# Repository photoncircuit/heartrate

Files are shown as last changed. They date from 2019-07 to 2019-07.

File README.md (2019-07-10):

# Heart Rate Monitoring System
Bachelors degree final project: portable heart rate monitoring system with bluetooth data transfer capability

The aim of this project is to design and construct a functional heart rate monitoring system. The device will amplify pulse measurements taken from an individual’s fingertip. The system is based on an active band pass filter which will amplify a selected signal frequency while attenuating noise and interference. Signals acquired from the fingertip sensor will be analogue and require conversion to digital. The use of an analogue to digital convertor (ADC) is employed in order for the microcontroller to process the information taken from the individual. After processing, the microcontroller will display pulse rate data on an LCD display and transmit the information wirelessly through the use of the Bluetooth communication protocol. It enables the user to move the device to any area desirable within their homes. A user can then view the transmitted data on an application, using a graphical user interface, running on their personal computers. Implementing this technology allows for users to easily monitor and log data about their personal health. The results collected from thorough testing indicate that even with precautions taken, noise and interference are still major causes of signal corruption.

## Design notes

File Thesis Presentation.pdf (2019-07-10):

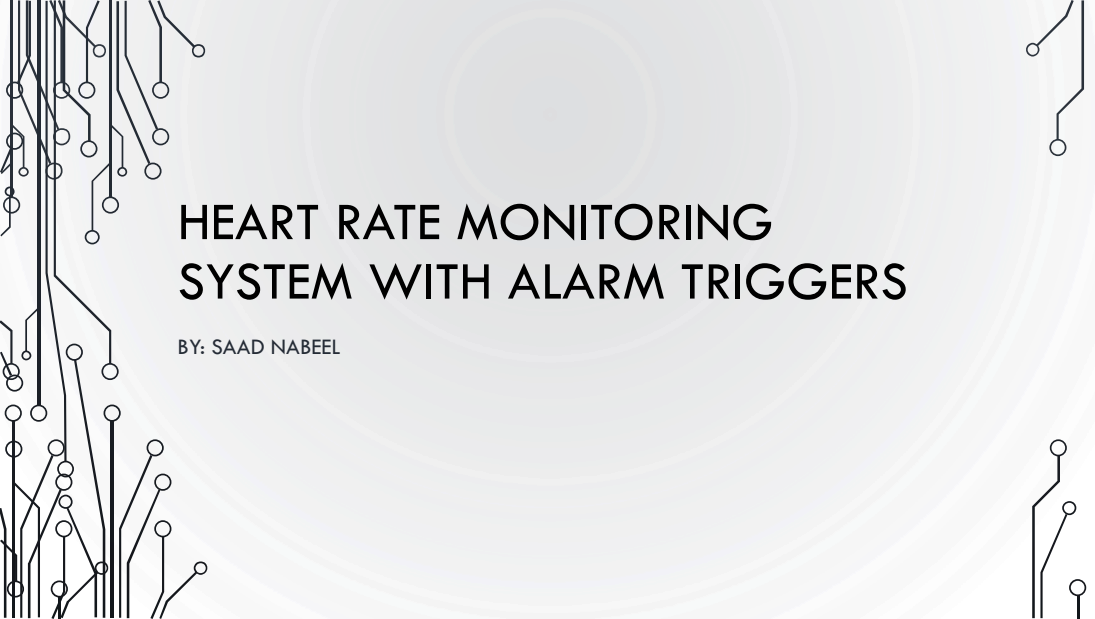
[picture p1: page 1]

HEART RATE MONITORING
SYSTEM WITH ALARM TRIGGERS

BY: SAAD NABEEL

# TABLE OF CONTENTS

## - Motivation

## - Objectives

## - Methodology

## - Specifications

## - Signal Conditioning

## - Analogue to Digital Conversion (ADC)

## - Schematic Diagram (Complete Circuit)

## - PIN Connections

## - Testing and Results

# MOTIVATION

## - Preventative measure for cardiac

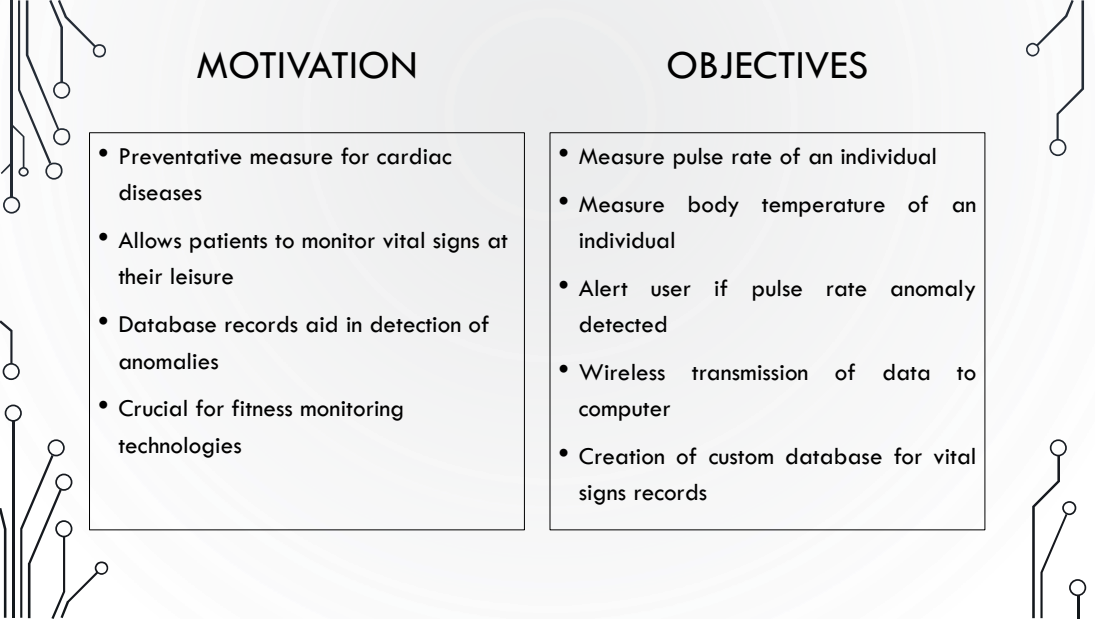
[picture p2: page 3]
OBJECTIVES; • Wireless transmission of; data to

• Measure pulse rate of an individual

diseases
• Allows patients to monitor vital signs at
their leisure
• Database records aid in detection of
anomalies
• Crucial for fitness monitoring
technologies

• Measure body temperature of an
individual
• Alert user if pulse rate anomaly
detected
computer
• Creation of custom database for vital
signs records

# METHODOLOGY

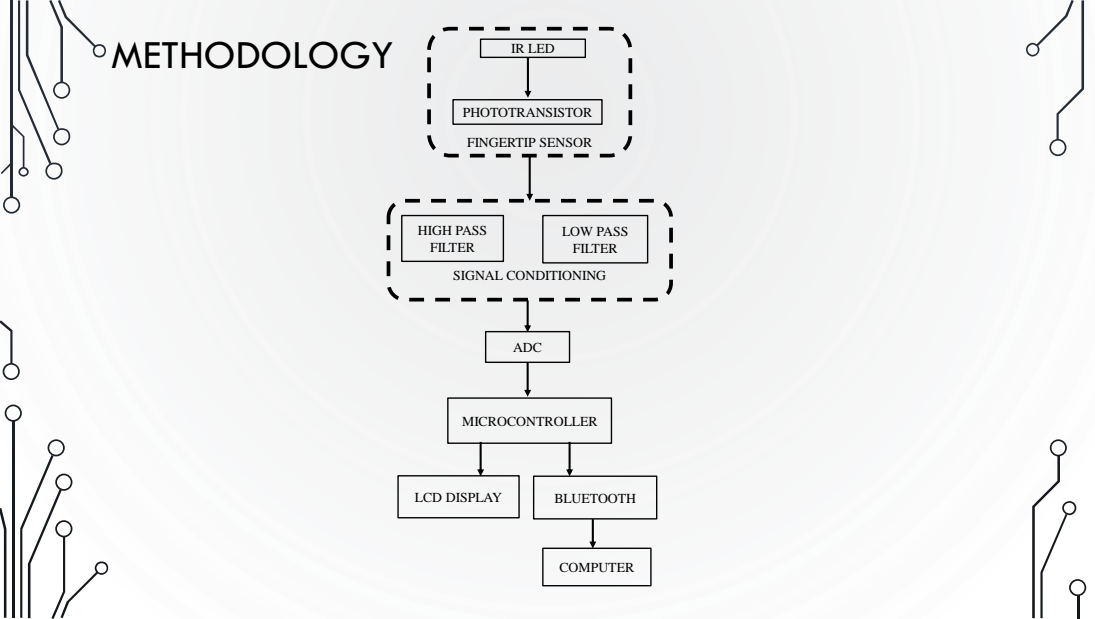
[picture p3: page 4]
FINGERTIP SENSOR; HIGH PASS FILTER; LOW PASS FILTER; SIGNAL CONDITIONING; ADC; MICROCONTROLLER; LCD DISPLAY; BLUETOOTH; COMPUTER; IR LED; PHOTOTRANSISTOR

# SPECIFICATIONS: OPTICAL SENSOR

## Main components: Infrared LED & Phototransistor

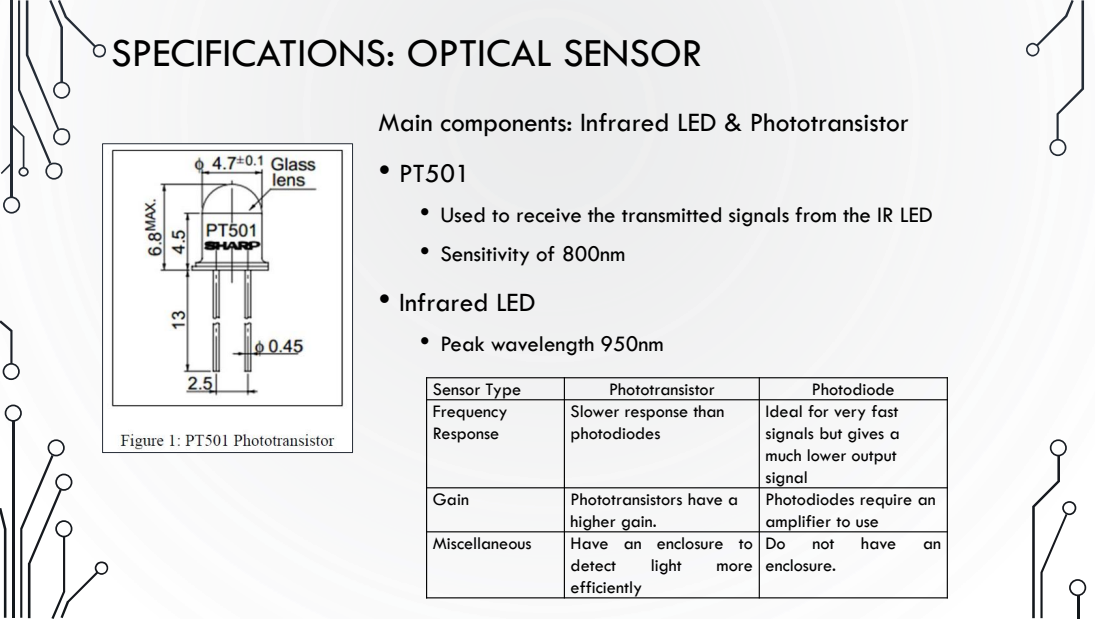
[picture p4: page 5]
• Sensitivity of 800nm; • Infrared LED; • Peak wavelength 950nm

• Used to receive the transmitted signals from the IR LED

Sensor Type | Phototransistor | Photodiode
Frequency Response | Slower response than photodiodes | Ideal for very fast signals but gives a much lower output signal

Gain | Phototransistors have a higher gain. | Photodiodes require an amplifier to use

Miscellaneous | Have an enclosure to detect light more efficiently | Do not have an enclosure.

# SPECIFICATIONS: OPERATIONAL AMPLIFIER

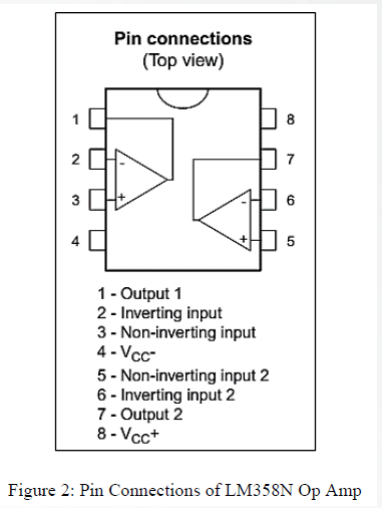
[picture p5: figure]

### - LM358N Operational Amplifier

### - Changes of blood volume picked up by the IR LED &

### phototransistor are too small to be read by microcontroller

### - Signal must be amplified in order to collect measurements

# SPECIFICATIONS: WIRELESS TRANSMISSION

### - Operating voltage: 3.3V

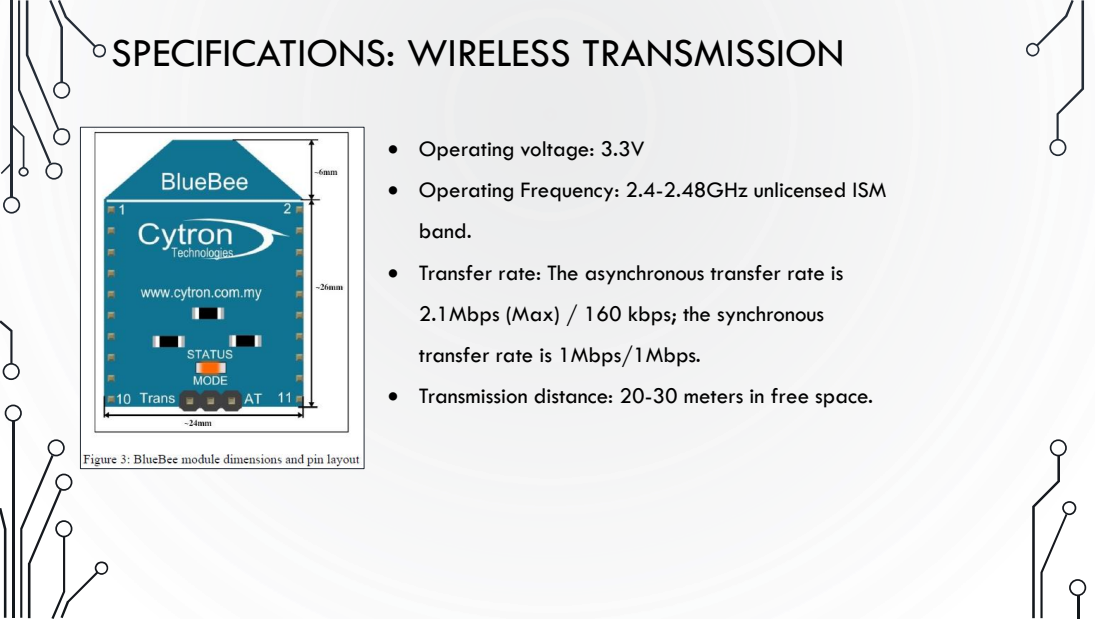
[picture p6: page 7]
band.

• Operating Frequency: 2.4-2.48GHz unlicensed ISM

• Transfer rate: The asynchronous transfer rate is

2.1Mbps (Max) / 160 kbps; the synchronous

transfer rate is 1Mbps/1Mbps.

• Transmission distance: 20-30 meters in free space.

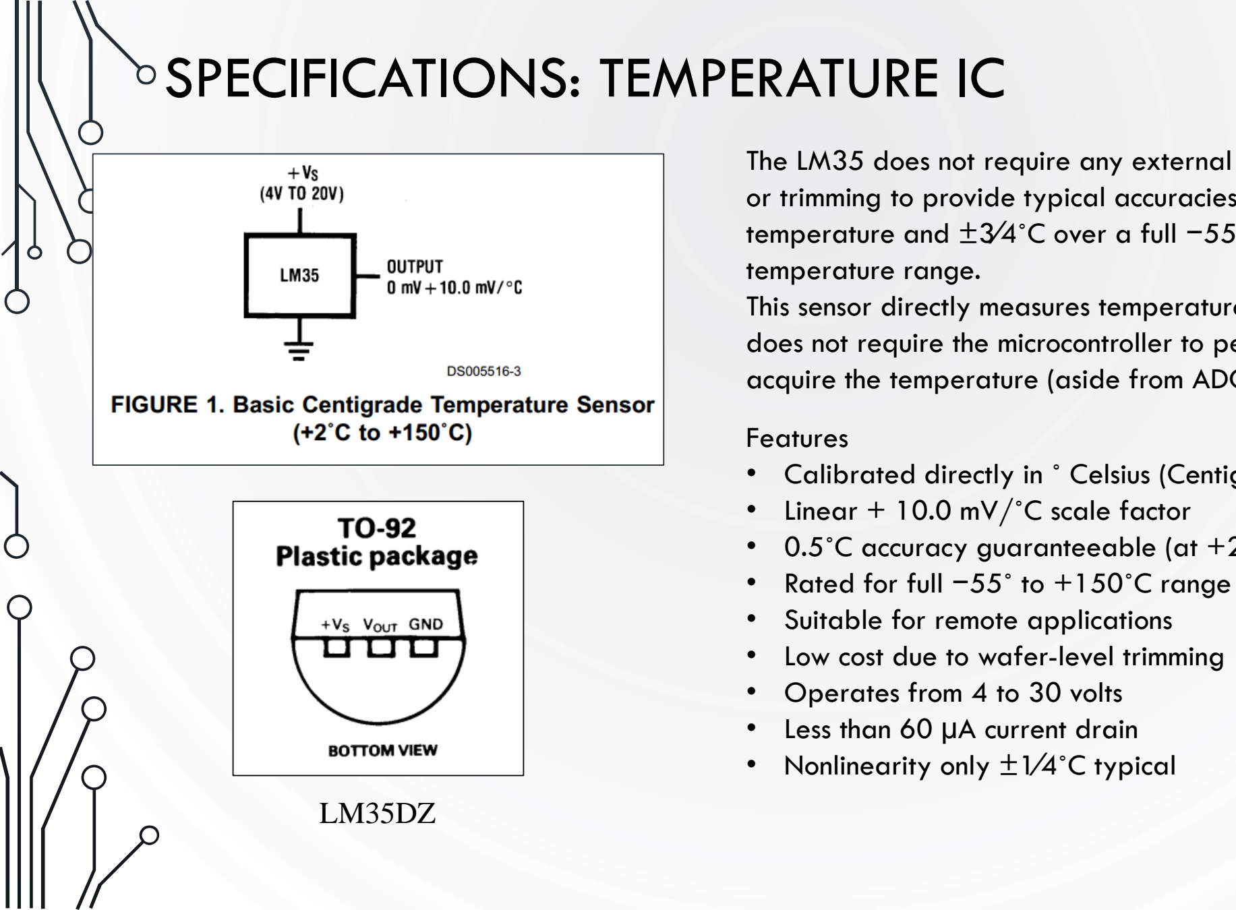
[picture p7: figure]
SPECIFICATIONS: TEMPERATURE IC; temperature range.; Features; • Linear + 10.0 mV/˚C scale factor; • Rated for full −55˚ to +150˚C range • Suitable for remote applications • Low cost due to wafer-level trimming • Operates from 4 to 30 volts • Less than 60 µA current drain • Nonlinearity only ±1⁄4˚C typical

The LM35 does not require any external calibration
or trimming to provide typical accuracies of ±1⁄4˚C at room temperature and ±3⁄4˚C over a full −55 to +150˚C

This sensor directly measures temperature in degrees Celsius and does not require the microcontroller to perform any equations to acquire the temperature (aside from ADC).

- Calibrated directly in ˚ Celsius (Centigrade)
- 0.5˚C accuracy guaranteeable (at +25˚C)

# SPECIFICATIONS: MICROCONTROLLER

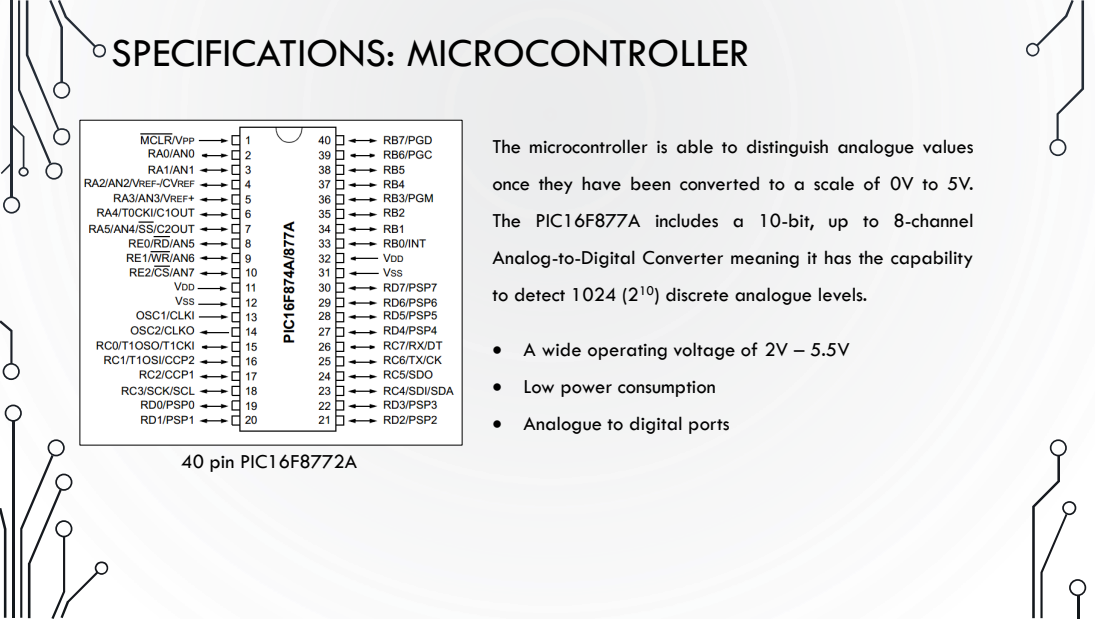
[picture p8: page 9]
to detect 1024 (2; 40 pin PIC16F8772A

The microcontroller is able to distinguish analogue values

once they have been converted to a scale of 0V to 5V.

The PIC16F877A includes a 10-bit, up to 8-channel

Analog-to-Digital Converter meaning it has the capability

10) discrete analogue levels.

• A wide operating voltage of 2V – 5.5V

• Low power consumption

• Analogue to digital ports

# SIGNAL CONDITIONING: LOW PASS FILTER

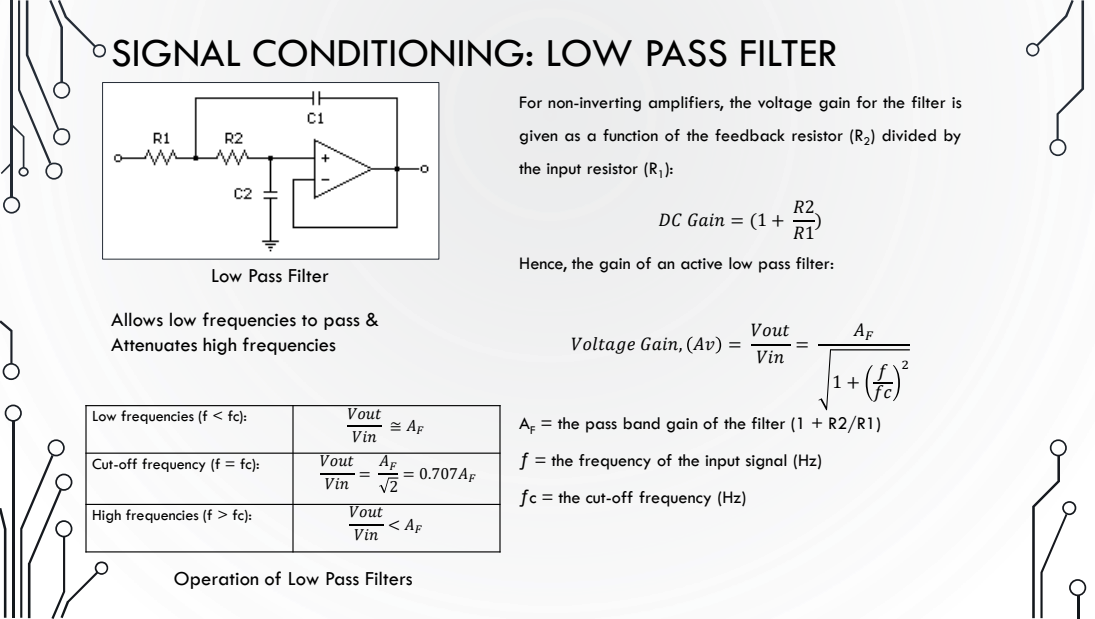
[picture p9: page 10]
) divided by; DC Gain = (1 +; Vout Vin =

For non-inverting amplifiers, the voltage gain for the filter is

given as a function of the feedback resistor (R2

the input resistor (R1

Hence, the gain of an active low pass filter:

Low Pass Filter

Allows low frequencies to pass &
Attenuates high frequencies

Voltage Gain, Av =

Low frequencies (f < fc): | Vout ≅ AF Vin

= the pass band gain of the filter (1 + R2/R1)

Cut-off frequency (f = fc): | Vout AF Vin = = 0.707AF 2

ƒ = the frequency of the input signal (Hz)

ƒc = the cut-off frequency (Hz)

High frequencies (f > fc): | Vout Vin < AF

Operation of Low Pass Filters

# SIGNAL CONDITIONING: HIGH PASS FILTER

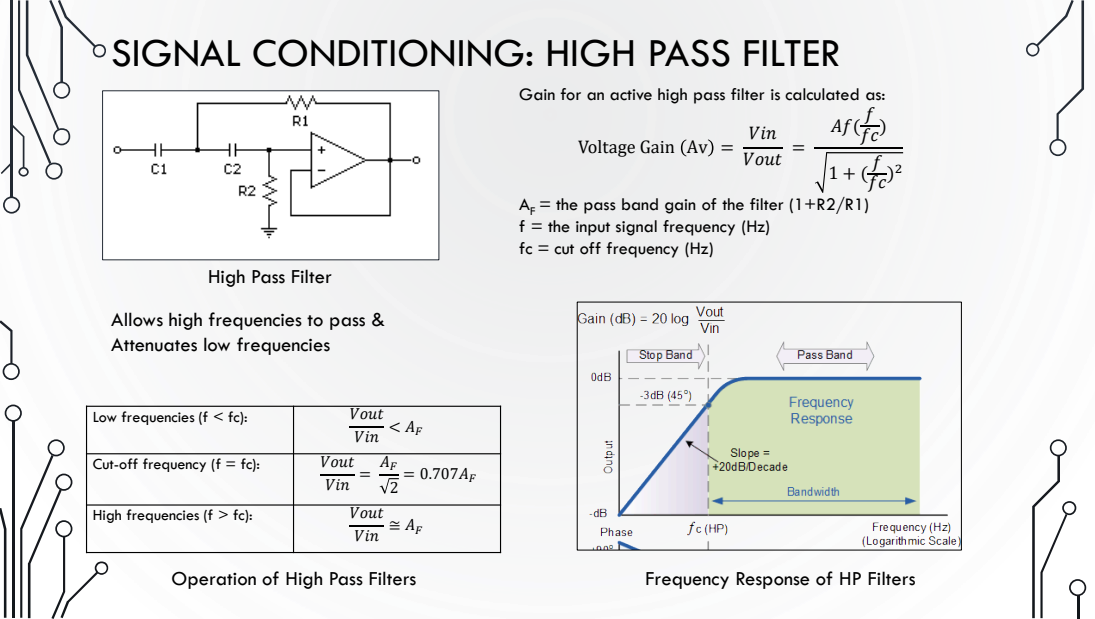
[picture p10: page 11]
Vin Vout =; Operation of High Pass Filters; Frequency Response of HP Filters

Gain for an active high pass filter is calculated as:

Voltage Gain Av =

AF = the pass band gain of the filter (1+R2/R1)
f = the input signal frequency (Hz)
fc = cut off frequency (Hz)

High Pass Filter

Allows high frequencies to pass &
Attenuates low frequencies

Low frequencies (f < fc): | Vout Vin < AF

Cut-off frequency (f = fc): | Vout AF Vin = = 0.707AF 2

High frequencies (f > fc): | Vout ≅ AF Vin

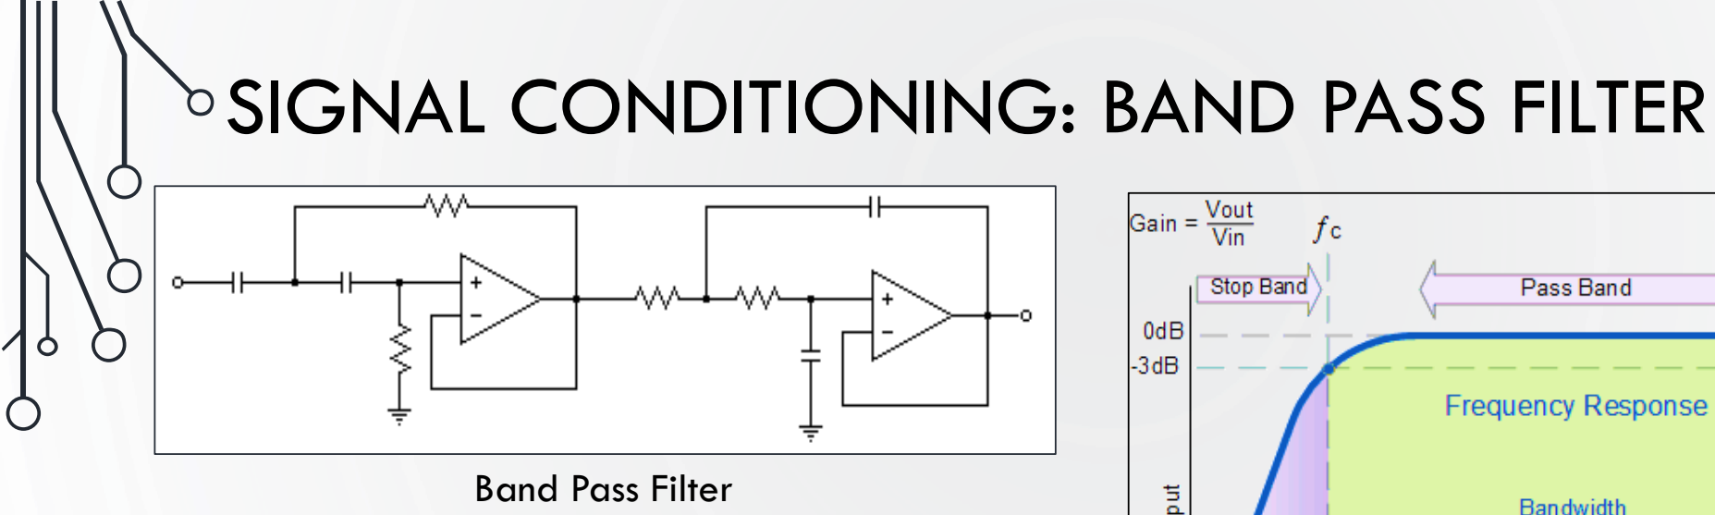
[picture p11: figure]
SIGNAL CONDITIONING: BAND PASS FILTER; Band Pass Filter

Band pass filters have two cut off frequency points which are the lower frequency and higher frequency and attenuate all other frequencies outside of these points

The cut off frequency of the low pass filter is greater than the cut off frequency of the high pass filter. The discrepancy between them at the -3dB point will decide the bandwidth of the band pass filter. The filter will block any signals outside these points.

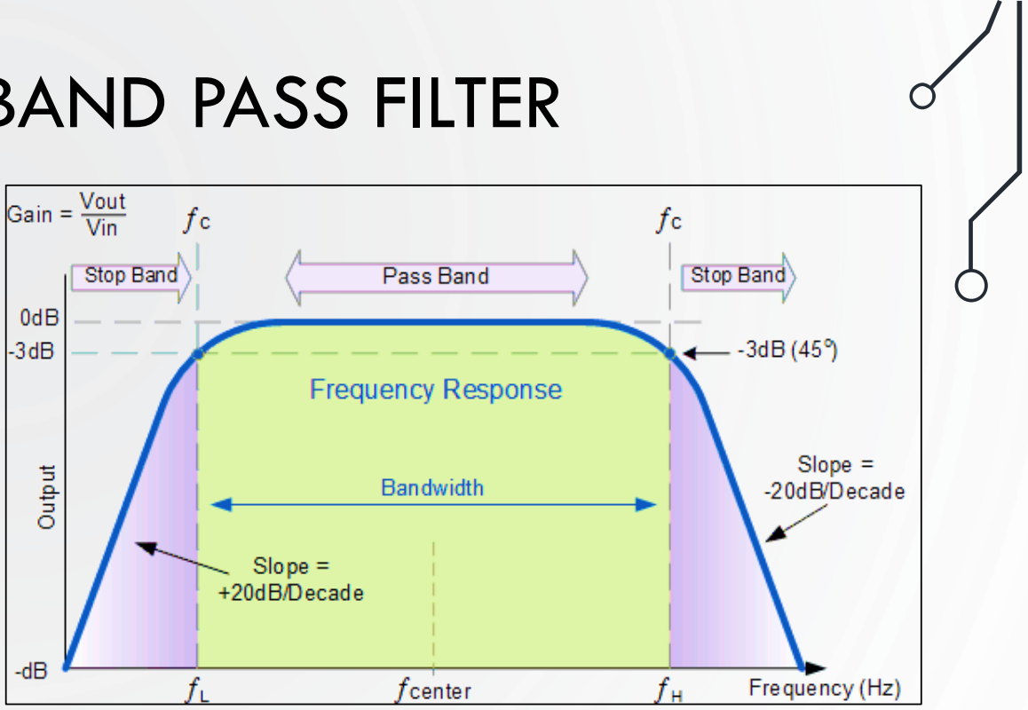
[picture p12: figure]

Frequency Response of a Band Pass Filter

The upper and lower frequencies of a band pass filter can be

found using the same formula used to calculate cut off

frequencies of high pass and low pass filters:

fc =

1
2πfRC Hz

# SIGNAL CONDITIONING: CIRCUIT

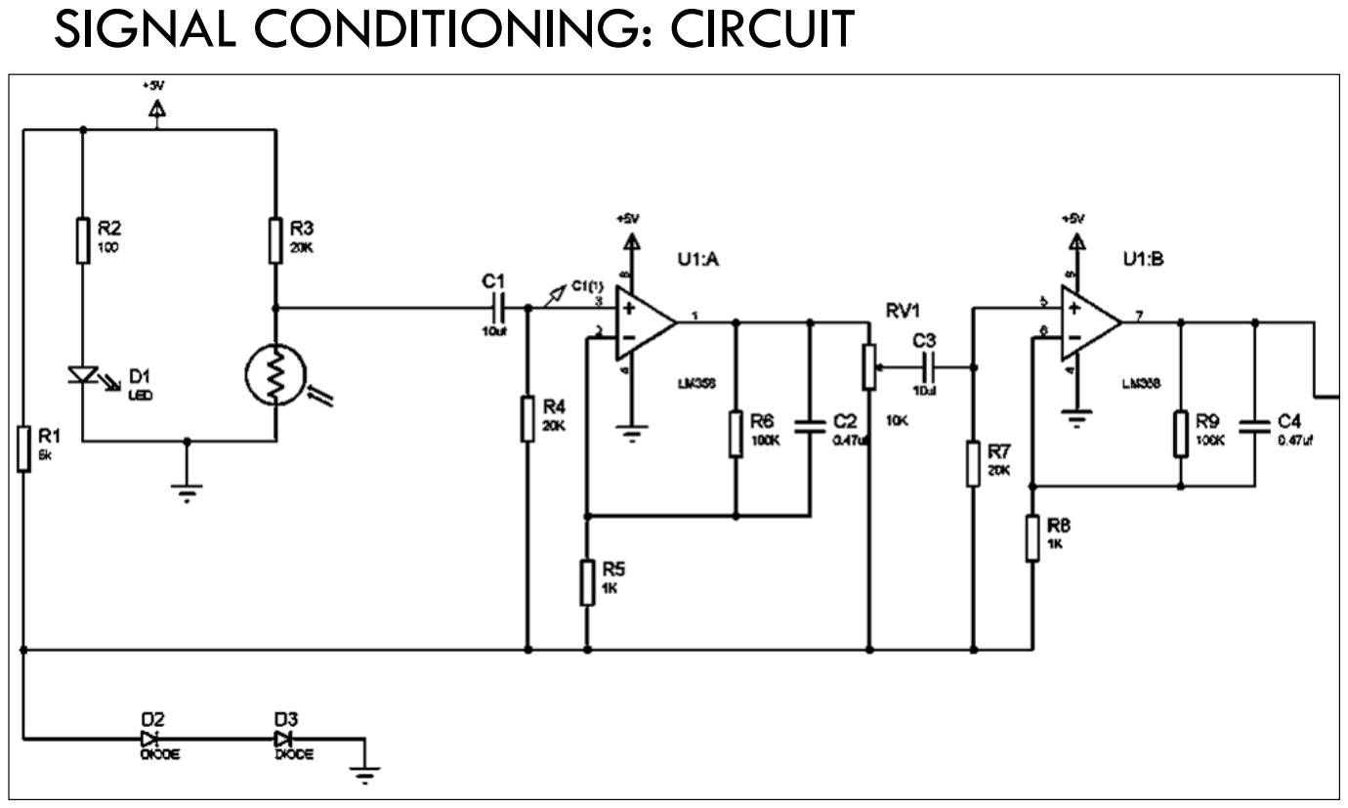
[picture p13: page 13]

# SIGNAL CONDITIONING

| Equation | Calculation
Gain of Non-Inverting Op Amp | Rf Gain Av = R1 + 1 Rf = 100KΩ R1 = 1KΩ | 100KΩ Av = 1KΩ + 1 = 101

The cut off frequency in a low pass filter is the point where high frequencies will be

attenuated and only low frequencies will be allowed to pass through. The cut off frequency

of a high pass filter is the point where only high frequencies can pass. Cascading the two

filters creates a band pass filter. To calculate the upper and lower cut off frequencies of

a band pass filter, the following equation is used:
Cut off frequency in Hertz, fc | 1 fc = 2πRC Hz R = 100KΩ C = 0.47µF | 1 fc = 2π 100KΩ 0.47µF = 3.386 Hz
Maximum Output Gain | fr² = fUpper x fLower | fr² = 3.386 Hz x 3.386 Hz = 11.464996 Hz

# ANALOGUE TO DIGITAL CONVERSION (ADC)

Code | Solution
input1 = adc_read(0)/4; if(input1>=128) | 1023/4 ≈ 255 255 128 5V = x x = 2.509 Volts If input 1 >= 2.5V, then it is HIGH
input1=adc_read(0)/4; if(input1<=45) | 255 45 = 5V x x = 0.88 Volts If input 1 <= 45, then it is LOW

Heart

Rate

The ADC conveys a ratio metric value, meaning the ADC fixes 5V to represent 1023 and anything less than 5V will be a ratio between 5V and 1023.

### Resolution of tℎe ADC System Voltage

=

### ADC Reading Analogue Voltage Measured

Since the system implemented in this project is using a 5V supply, a simple substitution can be done.

1023
5V

=

### ADC Reading Analogue Voltage Measured

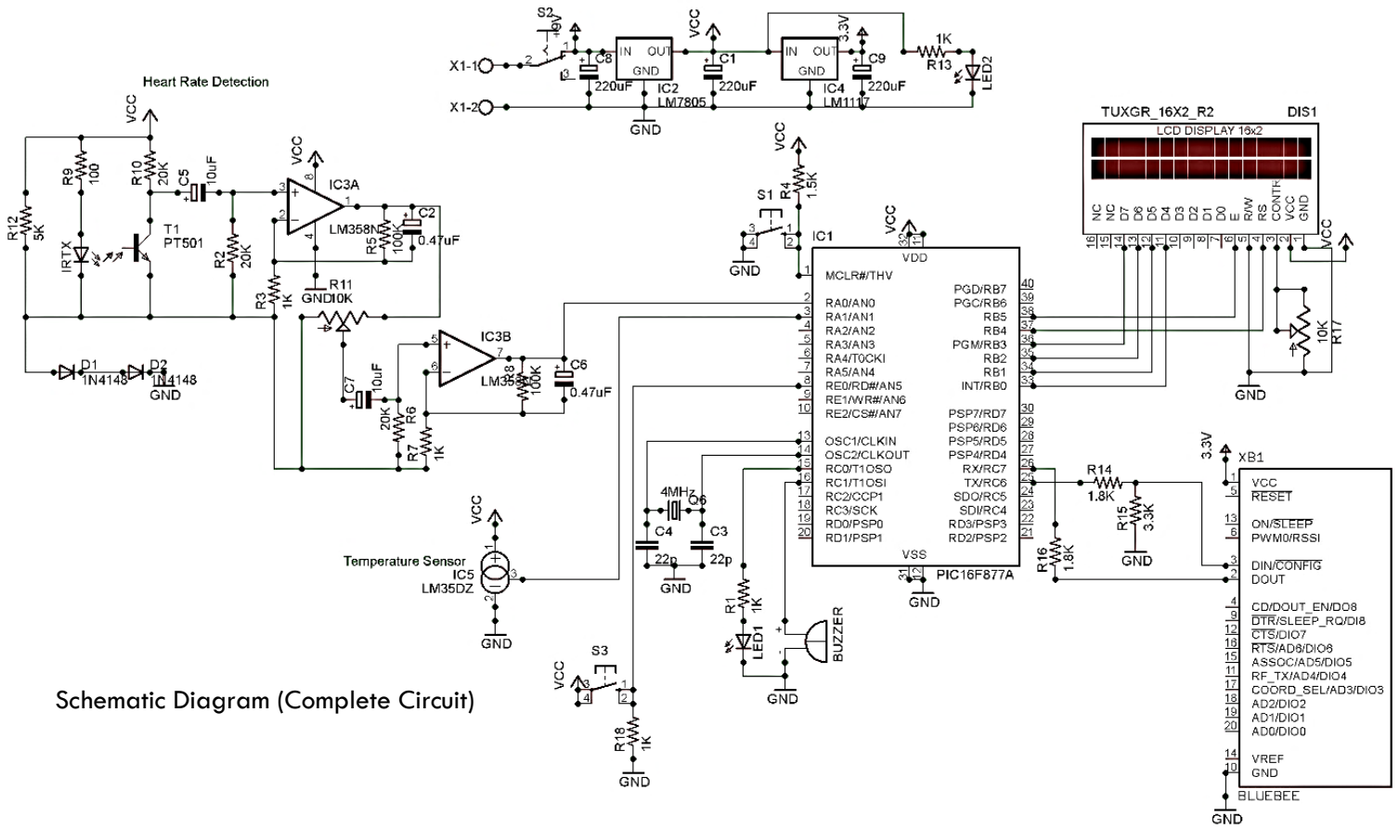
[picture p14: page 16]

Schematic Diagram (Complete Circuit)

# PIN CONNECTIONS

Pin # | Microcontroller Pins | Operation
1 | Master Clear (MCLR) | Resets the microcontroller
2 | AN0 | Used to attain analogue input from heart rate detection circuit
3 | AN1 | Used to attain readings from temperature sensor
8 | AN5 | Connected as switch which initiates the program in the microcontroller
13&1 4 | OSC1/CLKIN & OSC2/CLKOUT | Used to connect the crystal oscillator
15&1 6 | RC0 & RC1 | Used to connect the buzzer and LED
33-38 | RB0 - RB5 | Used to connect the LCD Display
25&2 6 | TX/RC6 & RX/RC7 | Used to connect the BlueBee module

# TESTING AND RESULTS: OP-AMP

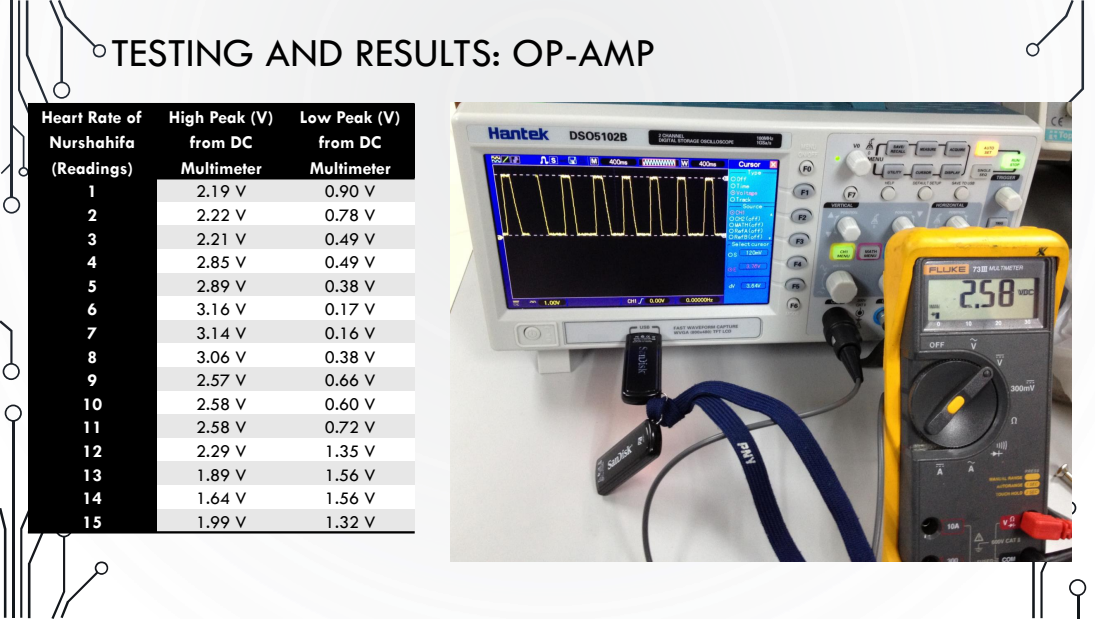
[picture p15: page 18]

Heart Rate of Nurshahifa (Readings) | High Peak (V) from DC Multimeter | Low Peak (V) from DC Multimeter

1 | 2.19 V | 0.90 V
2 | 2.22 V | 0.78 V
3 | 2.21 V | 0.49 V
4 | 2.85 V | 0.49 V
5 | 2.89 V | 0.38 V
6 | 3.16 V | 0.17 V
7 | 3.14 V | 0.16 V
8 | 3.06 V | 0.38 V
9 | 2.57 V | 0.66 V
10 | 2.58 V | 0.60 V
11 | 2.58 V | 0.72 V
12 | 2.29 V | 1.35 V
13 | 1.89 V | 1.56 V
14 | 1.64 V | 1.56 V
15 | 1.99 V | 1.32 V

# TESTING AND RESULTS: OP-AMP

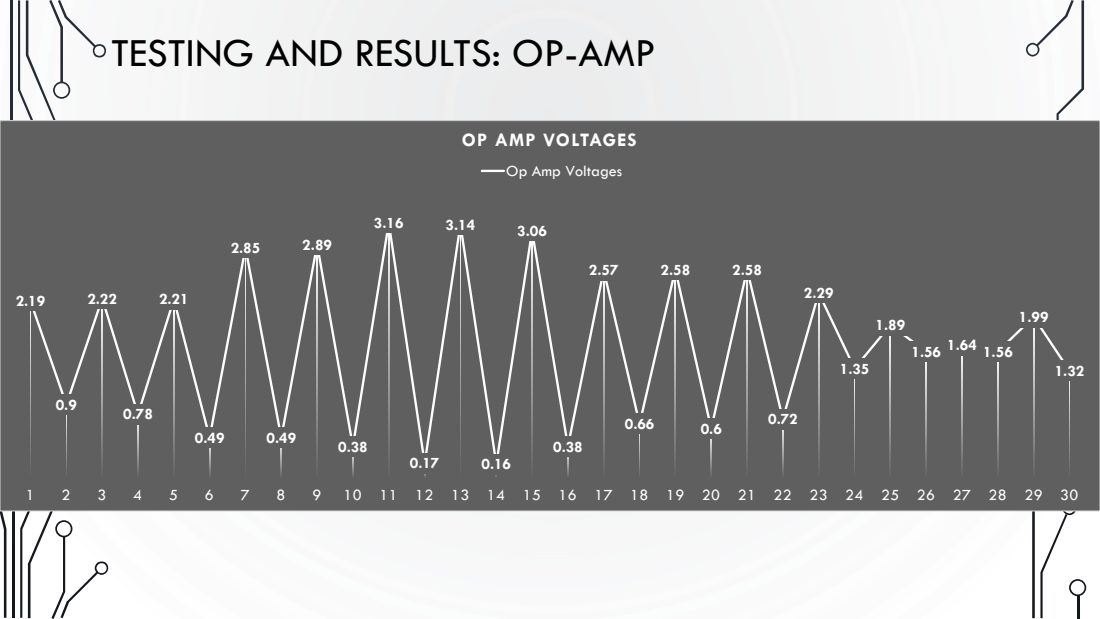
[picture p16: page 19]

OP AMP VOLTAGES

Op Amp Voltages

# TESTING AND RESULTS: PULSE DETECTION

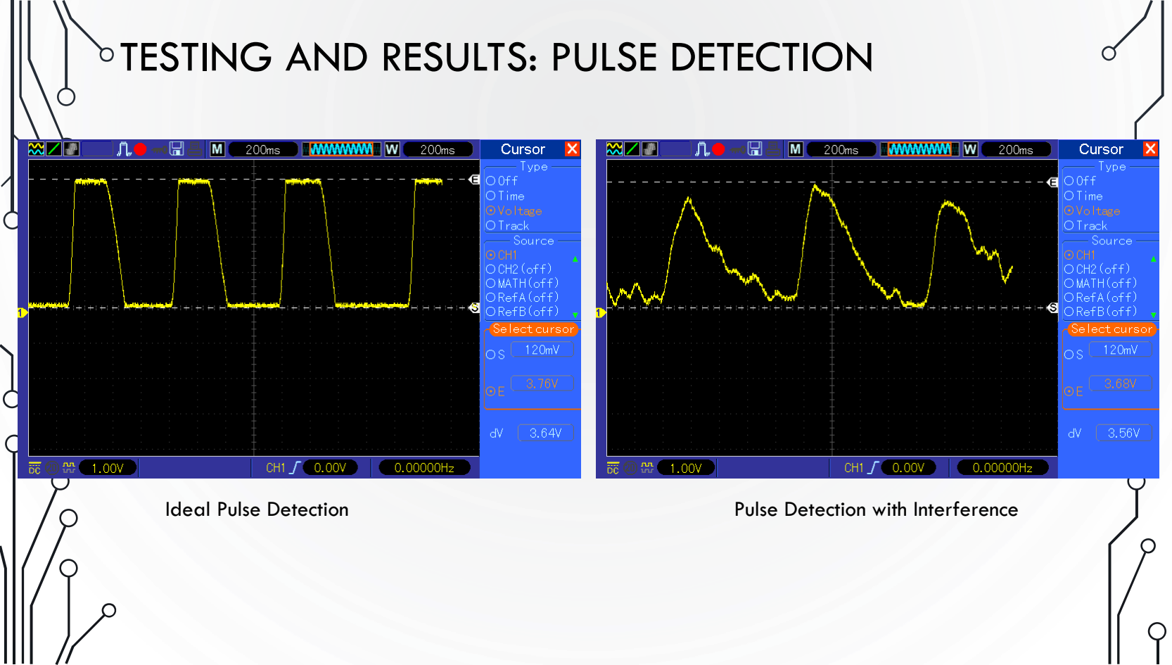
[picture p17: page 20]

Ideal Pulse Detection | Pulse Detection with Interference

# TESTING AND RESULTS: PULSE DETECTION

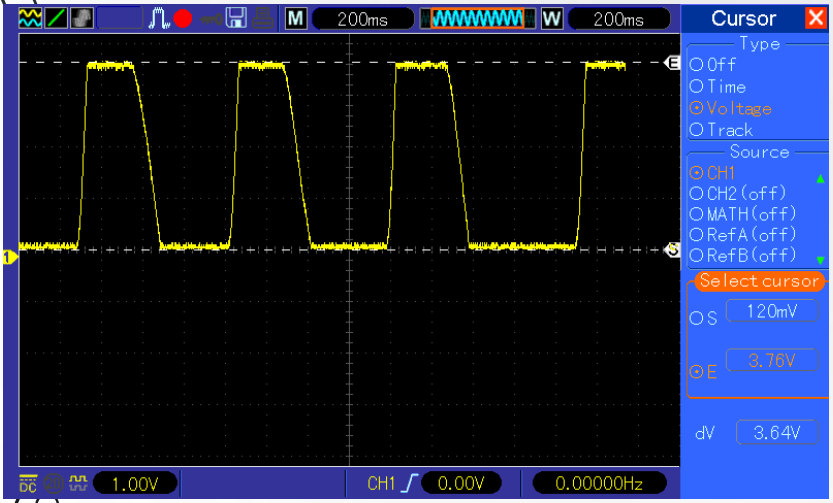
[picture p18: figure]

Ideal Pulse Detection

Each block on the plane shown represents a time

of 200ms on the x axis and a value of 1 volt on

the y-axis. The peak voltage achieved in the

heart rate of Saad Nabeel is 3.76V – 0.120V =

3.64 Volts. From this diagram it can be seen that

each cycle (beat) from a low peak to the next

subsequent low peak ranges approximately

800ms. Saad Nabeel’s heart rate can be

calculated by:

### 800ms × 5 cycles beats = 4 seconds

### equates to 5 beats every 4 seconds

### 5 beats 4 seconds

=

x

### 60 seconds

### x = 75 beats per minute

# TESTING AND RESULTS: RELIABILITY

## Heart Rate Sensor vs. Manual Counting

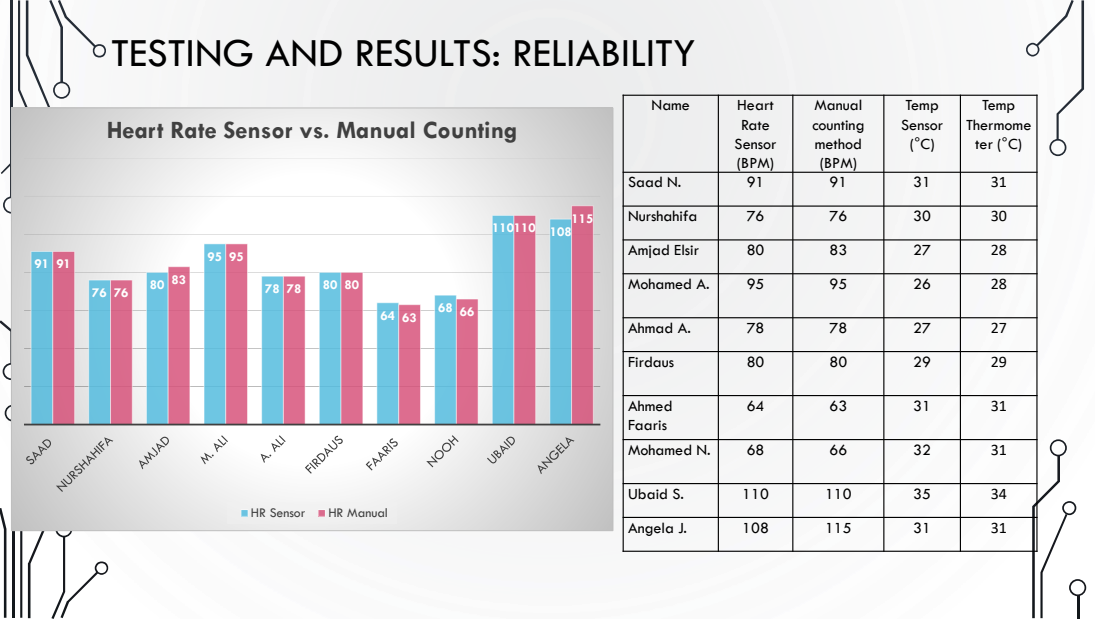
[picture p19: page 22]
HR Sensor; HR Manual

Name | Heart Rate Sensor (BPM) | Manual counting method (BPM) | Temp Sensor (°C) | Temp Thermome ter (°C)

Saad N. | 91 | 91 | 31 | 31

Nurshahifa | 76 | 76 | 30 | 30

Amjad Elsir | 80 | 83 | 27 | 28

Mohamed A. | 95 | 95 | 26 | 28

Ahmad A. | 78 | 78 | 27 | 27

Firdaus | 80 | 80 | 29 | 29

Ahmed Faaris | 64 | 63 | 31 | 31

Mohamed N. | 68 | 66 | 32 | 31

Ubaid S. | 110 | 110 | 35 | 34

Angela J. | 108 | 115 | 31 | 31

# TESTING AND RESULTS: VISUAL BASIC PROGRAM

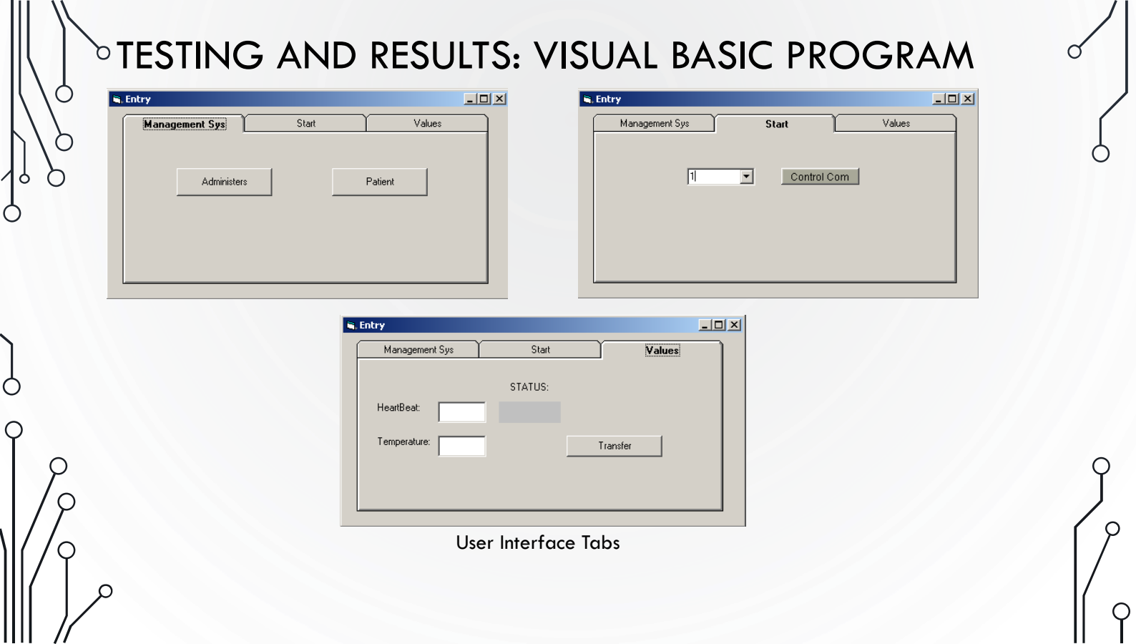
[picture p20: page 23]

User Interface Tabs

# TESTING AND RESULTS: VISUAL BASIC PROGRAM

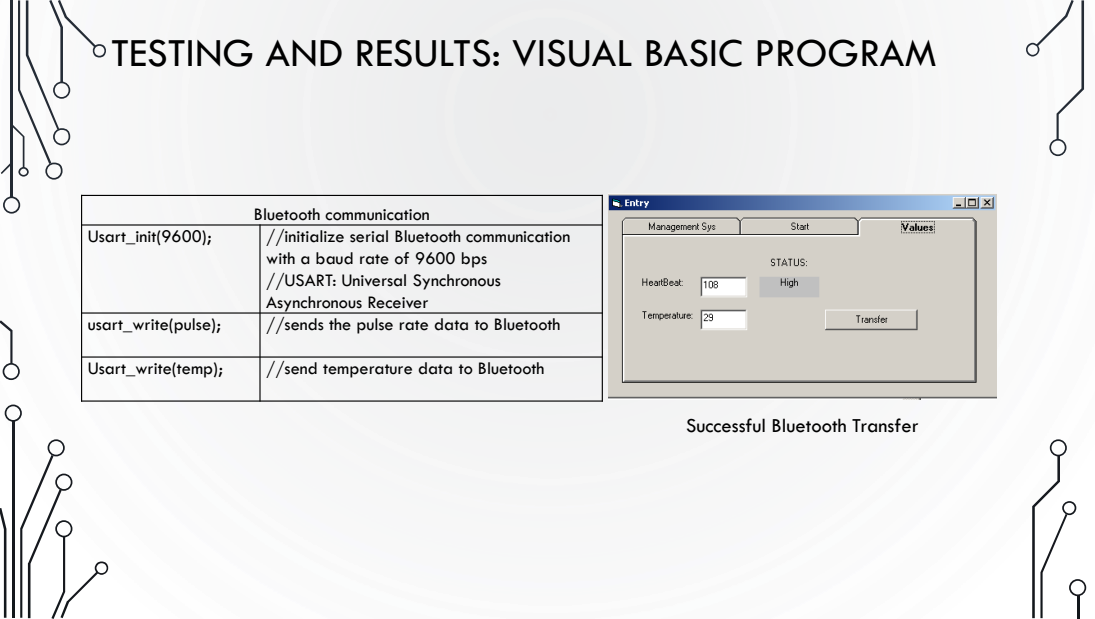
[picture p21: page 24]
Bluetooth communication

Usart_init(9600); | //initialize serial Bluetooth communication with a baud rate of 9600 bps //USART: Universal Synchronous Asynchronous Receiver

usart_write(pulse); | //sends the pulse rate data to Bluetooth

Usart_write(temp); | //send temperature data to Bluetooth

Successful Bluetooth Transfer

# TESTING AND RESULTS: VISUAL BASIC PROGRAM

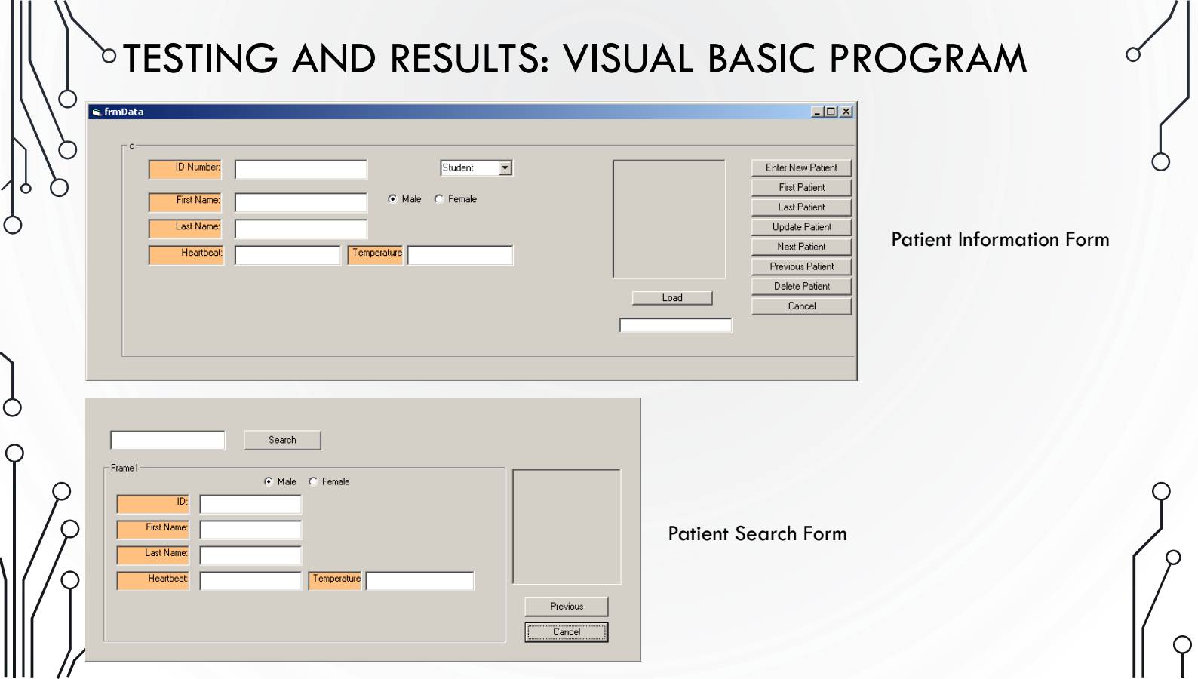
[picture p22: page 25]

Patient Information Form

Patient Search Form

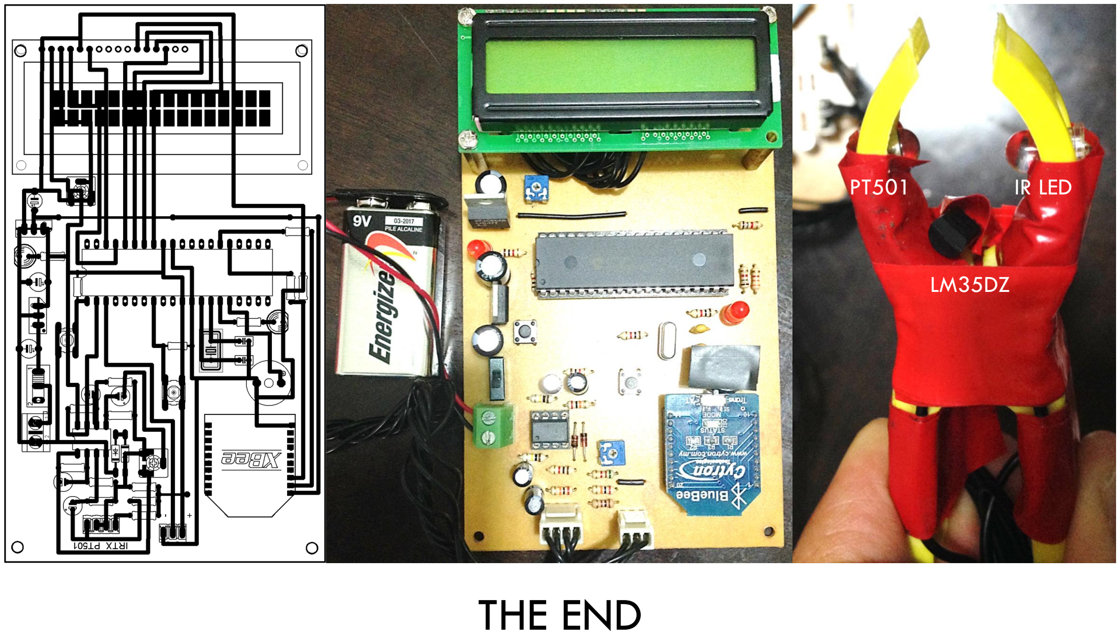
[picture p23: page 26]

# THE END

LM35DZ

PT501 | IR LED

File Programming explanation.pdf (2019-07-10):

## Programming

Programming the PIC16F877A microcontroller was done in the C programming language. This

section will highlight the main programming methods used in order to make this system

functional. (Note: The full code can be found in the Appendix.)

Setting up ports

ADCON1 =0b10001110;

TRISA = 0b00000011;

TRISB = 0b00000000;

TRISC = 0b00000000;

//setup analogue input for heartbeat detection

//setup porta as input

//portb is set as output

//portc and d is set as output

Table 12: Port set up code

Setting up the LCD display

LCD_Config(&PORTB,4,5,6,3,2,1,0);

Lcd_Init(&PORTB);

Lcd_Cmd(LCD_CLEAR);

Lcd_Cmd(LCD_CURSOR_OFF);

Lcd_Cmd(LCD_SECOND_ROW);

Lcd_Cmd(LCD_CLEAR);

lcd_out(1,1,"Heart Rate Monitor");

delay_ms(2000);

Lcd_Cmd(LCD_CLEAR);

//sets up the LCD port

// Initialize LCD connected to PORTB

// Clears the display

// Turns the LCD cursor off

//Clears the display

//Displays the introduction to the LCD

//wait 2 seconds

//Clears the display again

Table 13: LCD set up code

Measuring the heart rate and temperature

input1 = adc_read(0)/4;

if(input1>=128)

{
led=1;
buzzer=1;
pulse=pulse+1;
while(1)
{
if(sec_flag)
{
sec_flag=0;
count=count+1;
}
if(count>15)
break;

input1=adc_read(0)/4;
if(input1<=45)
{
led=0;
buzzer=0;
break;

//reads the input value as analogue and convert to digital

//if the input value > 128 == 2.5Volts, identify as a high peak

//turn LED on to indicate pulse
//beep the buzzer to indicate pulse //add 1 to the pulse count
//wait for the low peak from the signal

//wait for the 1 second flag

//keep counting seconds

//if the counter reaches 15 seconds, then timeout

//convert the input value (ADC)
//if the input value is < 45 == 0.88 volts, identify as low peak

//turn off the LED
//turn off the buzzer
//end from the loop
if(count>=15) { pulse=pulse*4; lcd_out(2,1,"BPM:"); inttostr(pulse,txt); | //if the count > 15 sec, execute the following //multiply pulse (15 sec) by 4 to get beats per minute //display pulse to the LCD
temp = adc_read(0x01)*2/4; | //read temperature value by converting ADC
lcd_out(1,1,"Temp:"); | //display temperature value on the LCD

Table 14: Heart rate and temperature sensing code

Bluetooth communication

Usart_init(9600); | //initialize serial Bluetooth communication with a baud rate of 9600 bps //USART: Universal Synchronous Asynchronous Receiver

usart_write(pulse); | //sends the pulse rate data to Bluetooth
Usart_write(temp); | //send temperature data to Bluetooth

Table 15: Bluetooth code

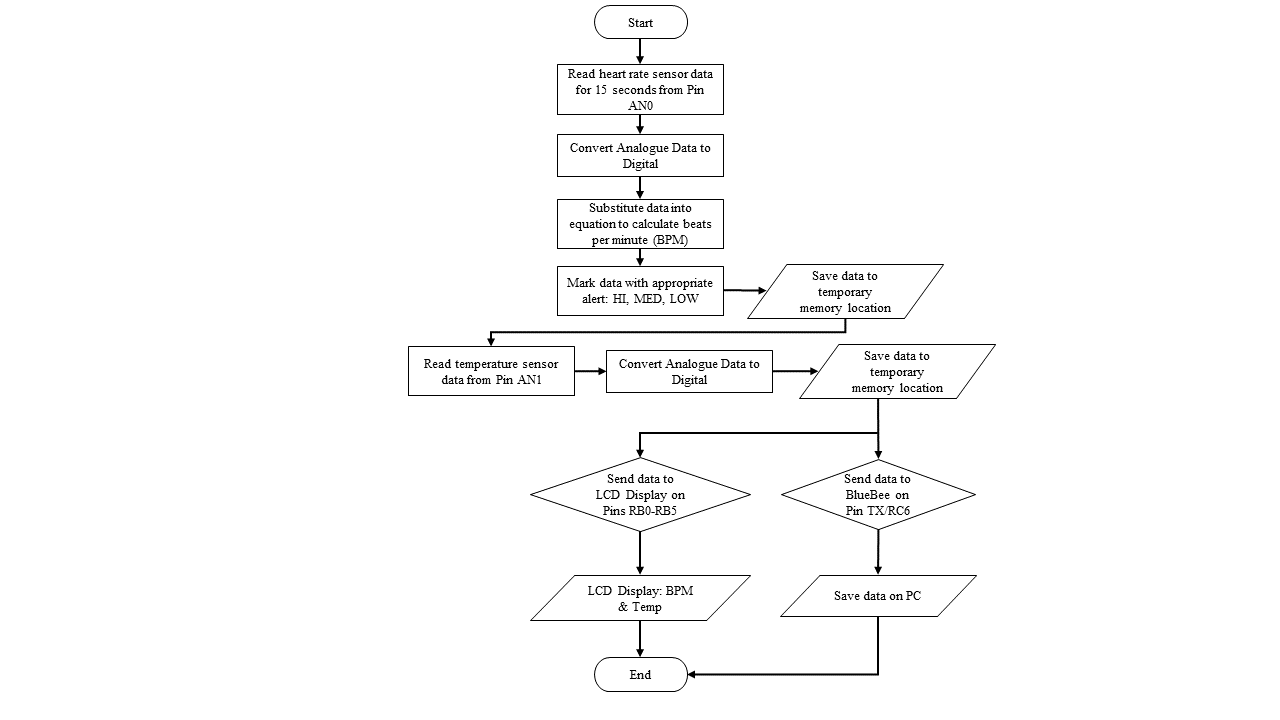
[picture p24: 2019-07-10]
Flowchart.png

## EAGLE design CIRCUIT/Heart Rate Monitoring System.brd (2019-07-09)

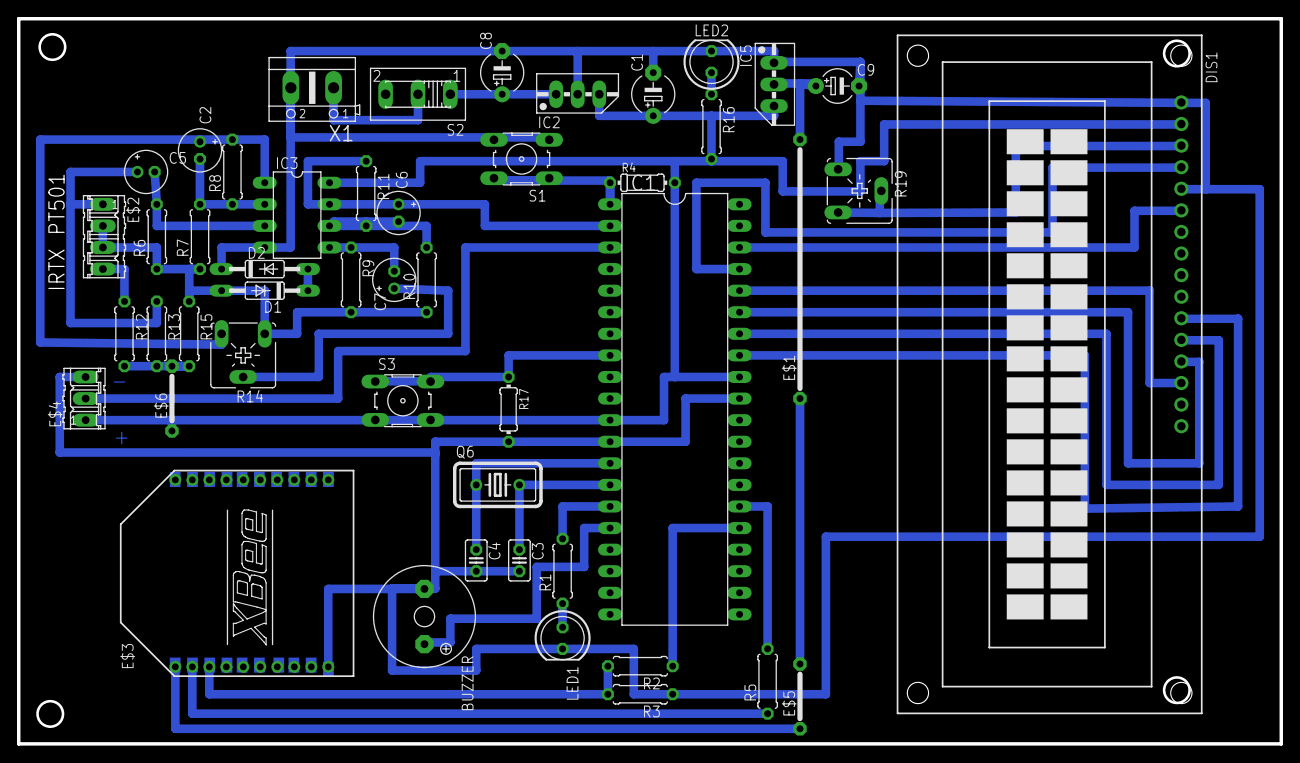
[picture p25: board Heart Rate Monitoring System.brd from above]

Board: 2 copper layers, 148.6 x 85.3 mm, 48 parts (0 on the bottom side), 39 nets.

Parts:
BUZZER: F/QMBIII
C1, C8: 220uF; E5-5
C2, C6: 0.47uF; E2-5
C3, C4: 22p; C025-025X050
C5, C7: 10uF; E2-5
C9: 220uF; E5-4
D1, D2: 1N4148; DO35-10
DIS1: TUXGR_16X2_R2
E$1: 30
E$2: 04P
E$3: BLUEBEE; XBEE
E$4: LM35DZ; 03P
E$5, E$6: 07
IC1: PIC16F877P; DIL40
IC2: LM7805; 78MXXS
IC3: LM358N; DIL08
IC5: LM1117; 78MXXS
LED1, LED2: LED5MM
Q6: 4MHz; HC18U-V
R1, R7, R10, R16: 1K; 0207/7
R2, R5: 1.8K; 0207/7
R3: 3.3K; 0207/7
R4, R17: 1.5K; 0204/7
R6, R9, R13: 20K; 0207/7
R8, R11: 100K; 0207/7
R12: 100; 0207/7
R14, R19: 10K; CA6V
R15: 5K; 0207/7
S1, S3: B3F-10XX
S2: 255SB
X1: AK500/2

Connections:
GND: BUZZER.-, C1.-, C3.2, C4.2, C8.-, C9.-, D2.C, DIS1.1, DIS1.5, E$3.10, E$4.3, IC1.12, IC1.31, IC2.GND, IC3.4, IC5.IN, LED1.K, LED2.K, R3.1, R17.2, R19.A, S1.3, S1.4, X1.2
unnamed: C2.+, IC3.1, R8.2, R14.E
unnamed: C5.-, IC3.3, R6.2
unnamed: S2.2, X1.1
unnamed: IC1.1, R4.1, S1.1, S1.2
unnamed: C3.1, IC1.14, Q6.2
unnamed: LED1.A, R1.1
unnamed: IC1.15, R1.2
unnamed: BUZZER.+, IC1.16
unnamed: C2.-, IC3.2, R7.2, R8.1
unnamed: C7.+, R14.S
unnamed: C7.-, IC3.5, R9.1
unnamed: C6.+, IC1.2, IC3.7, R11.1
unnamed: C6.-, IC3.6, R10.2, R11.2
unnamed: C5.+, E$2.1, R13.1
unnamed: C4.1, IC1.13, Q6.1
unnamed: E$2.4, R12.1
unnamed: D1.C, D2.A
unnamed: D1.A, E$2.2, E$2.3, R6.1, R7.1, R9.2, R10.1, R14.A, R15.1
unnamed: E$3.2, R5.1
unnamed: IC1.25, R2.1
unnamed: E$3.3, R2.2, R3.2
unnamed: IC1.26, R5.2
unnamed: DIS1.11, IC1.33
unnamed: DIS1.12, IC1.34
unnamed: DIS1.13, IC1.35
unnamed: DIS1.6, IC1.38
unnamed: DIS1.3, R19.E, R19.S
unnamed: DIS1.14, IC1.36
unnamed: DIS1.4, IC1.37
S$1: E$4.2, IC1.3
S$2: C9.+, E$1.2, IC5.GND
S$3: IC1.8, R17.1, S3.1, S3.2
S$4: E$6.2, R12.2, R13.2, R15.2
S$5: E$1.1, E$5.2
S$23: LED2.A, R16.1
S$24: E$3.1, E$5.1
V+: C8.+, IC2.IN, S2.1
VCC: C1.+, DIS1.2, E$4.1, E$6.1, IC1.11, IC1.32, IC2.OUT, IC3.8, IC5.OUT, R4.2, R16.2, S3.3, S3.4

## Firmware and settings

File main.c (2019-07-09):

//define pin used
#define sec_flag flag.F0      //sec timer
#define start_flag flag.F1    //start flag
#define led PORTC.F0          //led & buzzer pin
#define buzzer PORTC.F1
#define enter PORTE.F0

char msec,sec,minutes,hour;       //declare variables
int pulse;
char count,flag;
char txt[10];
char group;
char temp;

//define timer intterupt
//interupt cycle within interupt flag expires
//1msec
 void interrupt(){	                        //clock that is needed to time the heart rate.

  if  (INTCON.T0IF){ 	                     //interupt control - timer 0 expired
      asm{clrwdt}	                        //clear the watchdog timer in assembly - prevents PIC from failing
      msec++;                             //msec+1
      if (msec >100){
         msec = 0;
         sec++;                          //if more than 100 then sec+1
         sec_flag=1;
           if (sec >=60){                //if sec>60 then min+1
             sec = 0;
             minutes++;
               if (minutes >=60){       //if min > 60 then hour+1
                  minutes = 0;
                  hour++;
                     if (hour >=24){
                        hour = 0;
                     }
               }
           }
       }
  }
//  TMR0=0x00;
  TMR0  = 0   ;
  INTCON = 0x20;       // Set T0IE, clear T0IF    - restore original values
}

//set function prototype
void beep();
void ok();
void fail();
void set_group();
void error();
void healthy();
void unhealthy();

char ip1;

//main routine
void main()
{
  ADCON1 =0b10001110;                   //setup analogue for heartbeat
  TRISA = 0b00000011;                   //setup porta as input
  TRISB = 0b00000000;                   //portb as output
  TRISC = 0b00000000;                   //portc & d as output
  TRISD = 0b00000000;
  TRISE = 0b00000111;
  PORTA = 0b00000000;                   //clears all ports
  PORTB = 0b00000000;
  PORTC = 0b00000000;
  PORTD = 0b00000000;
  PORTE = 0x00;
  OPTION_REG = 0b00000101;              //timer ratio for intterupt
//  T0CON = 0b11000101;
  LCD_Config(&PORTB,4,5,6,3,2,1,0);     //setup LCD port
  Lcd_Init(&PORTB);                     // Initialize LCD connected to PORTB
  Lcd_Cmd(LCD_CLEAR);                   // Clear display
  Lcd_Cmd(LCD_CURSOR_OFF);              // Cursor off
  Lcd_Cmd(LCD_SECOND_ROW);
  Lcd_Cmd(LCD_CLEAR);                   // Clear display
  lcd_out(1,1,"Heartbeat Meter");       //display intro at lcd
  delay_ms(2000);
  Lcd_Cmd(LCD_CLEAR);                   // Clear display
  Usart_init(9600);                     //setup serial Bluetooth communication with a baud rate of 9600 bps
  sec=0;                                //clears all registers
  count=0;
  pulse=0;
  start_flag=0;	                        //push button - when pressed, then will turn to 1 (on)
  group=0;
  Lcd_out(1,1,"Standby");               //display standby
//main loop
  do
  {

//   set_group();
   if(enter)                            //wait to press enter
   {
    Lcd_out(1,1,"Start  ");             //display start and start the counting flag
    start_flag=1;
   }

   if(start_flag)                       //if flag detected
   {
     if(sec_flag)                       //wait for 1 sec flag
     {
      sec_flag=0;
      count=count+1;                    //count + 1 after every 1 sec
     }

     if(count>=15)                      //if the count > 15 sec, execute the following
     {
      pulse=pulse*4;                    //multiply pulse (15 sec) by 4 to get beats per minute
      lcd_out(2,1,"BPM:");
      inttostr(pulse,txt);              //display pulse to the LCD
      lcd_chr_cp(txt[2]);               //display lcd arrays
      lcd_chr_cp(txt[3]);
      lcd_chr_cp(txt[4]);
      lcd_chr_cp(txt[5]);
      beep();                           //beep 2x
      beep();
      usart_write(pulse);               //send pulse to bluetooth
      temp = adc_read(0x01)*2/4;        //read temperature value by converting ADC
      Usart_write(temp);                //send temp to bluetooth
      lcd_out(1,1,"Temp:");             //display temperature value to lcd
      bytetostr(temp,txt);
      lcd_chr_cp(txt[0]);
      lcd_chr_cp(txt[1]);
      lcd_chr_cp(txt[2]);
      count=0;
 //     pulse=0;
      start_flag=0;
      if(pulse>=95)
      lcd_out(1,10,"High");
      else if(pulse>=60)
      lcd_out(1,10,"Med ");
      else
      lcd_out(1,10,"Low ");
      delay_ms(3000);                   //delay 3sec


      Lcd_Cmd(LCD_CLEAR);               // Clear display
      Lcd_out(1,1,"Standby");           //display standby again
      pulse=0;
     }

     ip1 = adc_read(0)/4;               //read as analogue convert to digital
     if(ip1>=128)                       //if input > 128 == 2.5Volts as  a high peak
     {
      led=1;                            //led on
      buzzer=1;                         //buzzer
      pulse=pulse+1;                    //pulse  + 1
      while(1)                          //wait for low peak
      {
       if(sec_flag)                     //wait for 1sec flag
       {
        sec_flag=0;
        count=count+1;                  //keep counting sec
       }
       if(count>15)                     //if counter 15 sec then timeout
       break;
       ip1=adc_read(0)/4;               //convert adc
       if(ip1<=45)                      //if ip <45 == 0.7 volts
       {
        led=0;                          //off led
        buzzer=0;                       //off led
        break;                          //break from loop
       }
      }
     }


    }

  }while(1);
}

//****************************************

void beep(void)             //beeps the buzzer
{
 buzzer=1;
 delay_ms(100);
 buzzer=0;
 delay_ms(100);
}
